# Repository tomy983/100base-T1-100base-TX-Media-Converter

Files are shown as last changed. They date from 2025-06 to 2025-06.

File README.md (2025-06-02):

# 100base-T1-100base-TX-Media-Converter
PCB designed to convert automotive ethernet 100base-T1 to 100base-TX ethernet

This is a corrected version (the picture shows the previous revision). The correction consists of a missing resistor to set the TJA1101B MDIO address.

Another issue I had during bring up was the ferrite bead FB1, which I originally selected of incorrect value. (The TJA1101B was reporting low voltage on register 25 bits 15 and 14 (UV_VDDD_3V3 and UV_VDDA_3V3). I corrected it in the published schematic, but it is untested. On my PCB I've just shorted it.

I've tested 2 of this board with Unshielded and not twisted wire (ideally should be Twisted - UTP) of 8 meters length, reaching a speed of 85Mbps. No dropped packets were observed.
The polarity of the 2 wire ethernet doesn't really matter (the slave will correct accordingly).
After this successful test I've proceeded testing with my PandarQT 3D lidar (which only has 100base-T1 interface) successfully.

No MDIO setup is needed (the configuration is all done via strapping resistors). Just bridge the solder bridges to select autonomous mode and also master or slave as needed.
While not required, if you need MDIO interface to check / set registers, keep in mind that while in autonomous mode the MDIO interface of TJA1101B will not work. Just set it to managed.

Is included the very rough Arduino sketch that I've used to interface with MDIO (bit banging).

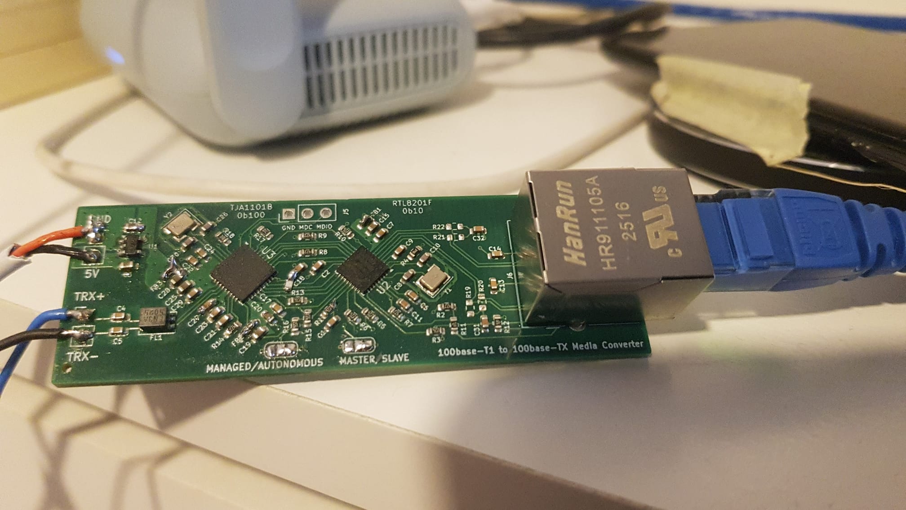
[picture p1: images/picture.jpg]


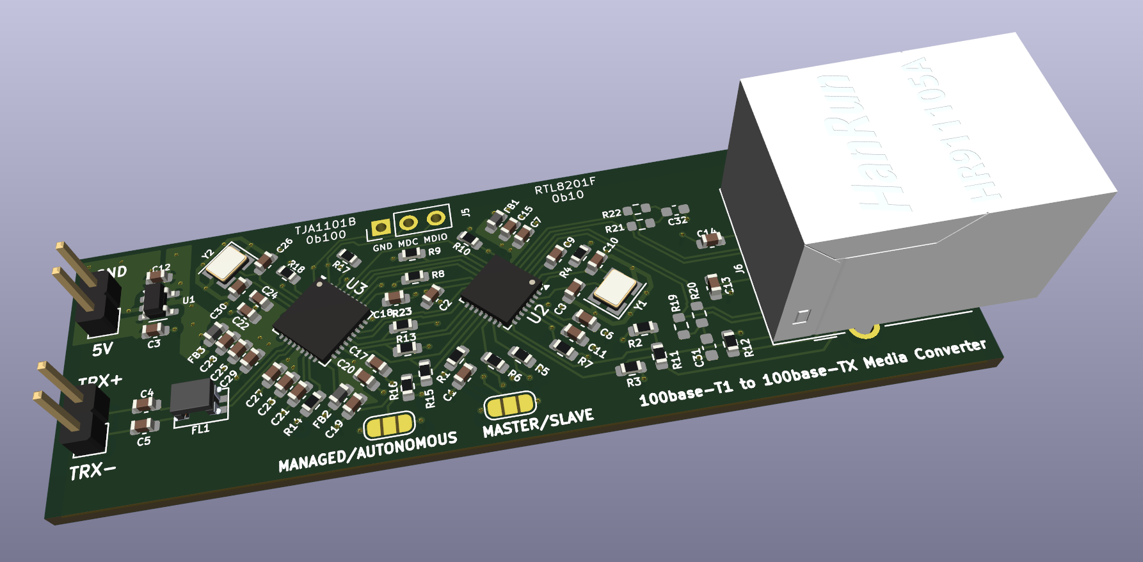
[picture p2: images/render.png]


Resources used for this project:

- https://www.nxp.com/downloads/en/schematics/RDDRONE-T1ADAPT-SCH.pdf
- https://github.com/NXPHoverGames/RDDRONE-T1ADAPT/blob/main/t1eth10Lpc/src/t1eth10Lpc.c
- https://github.com/ehntoo/100base-t1-converter
- https://www.nxp.com/document/guide/getting-started-with-the-rddrone-t1adapt-evaluation-board:GS-RDDRONE-T1ADAPT
- https://github.com/cioban/arduino-projects/blob/master/smi/smi.ino

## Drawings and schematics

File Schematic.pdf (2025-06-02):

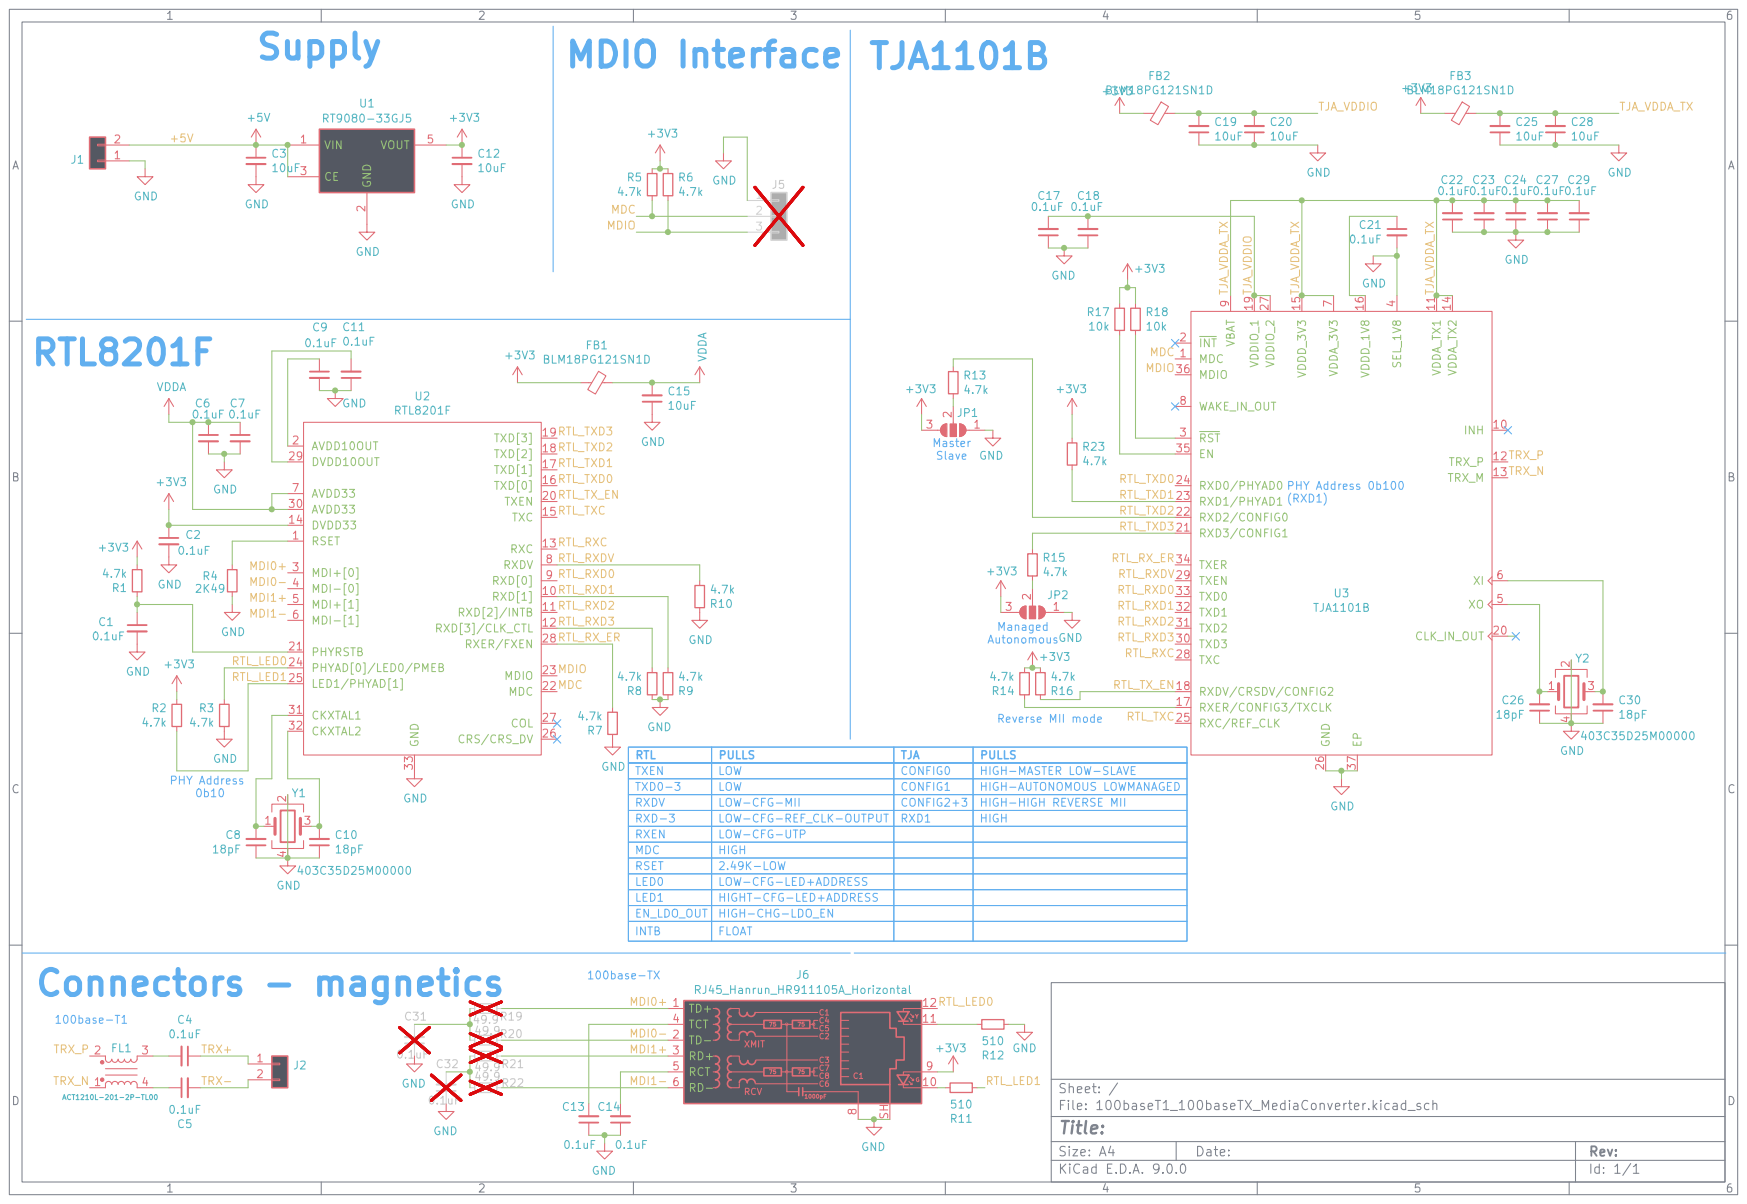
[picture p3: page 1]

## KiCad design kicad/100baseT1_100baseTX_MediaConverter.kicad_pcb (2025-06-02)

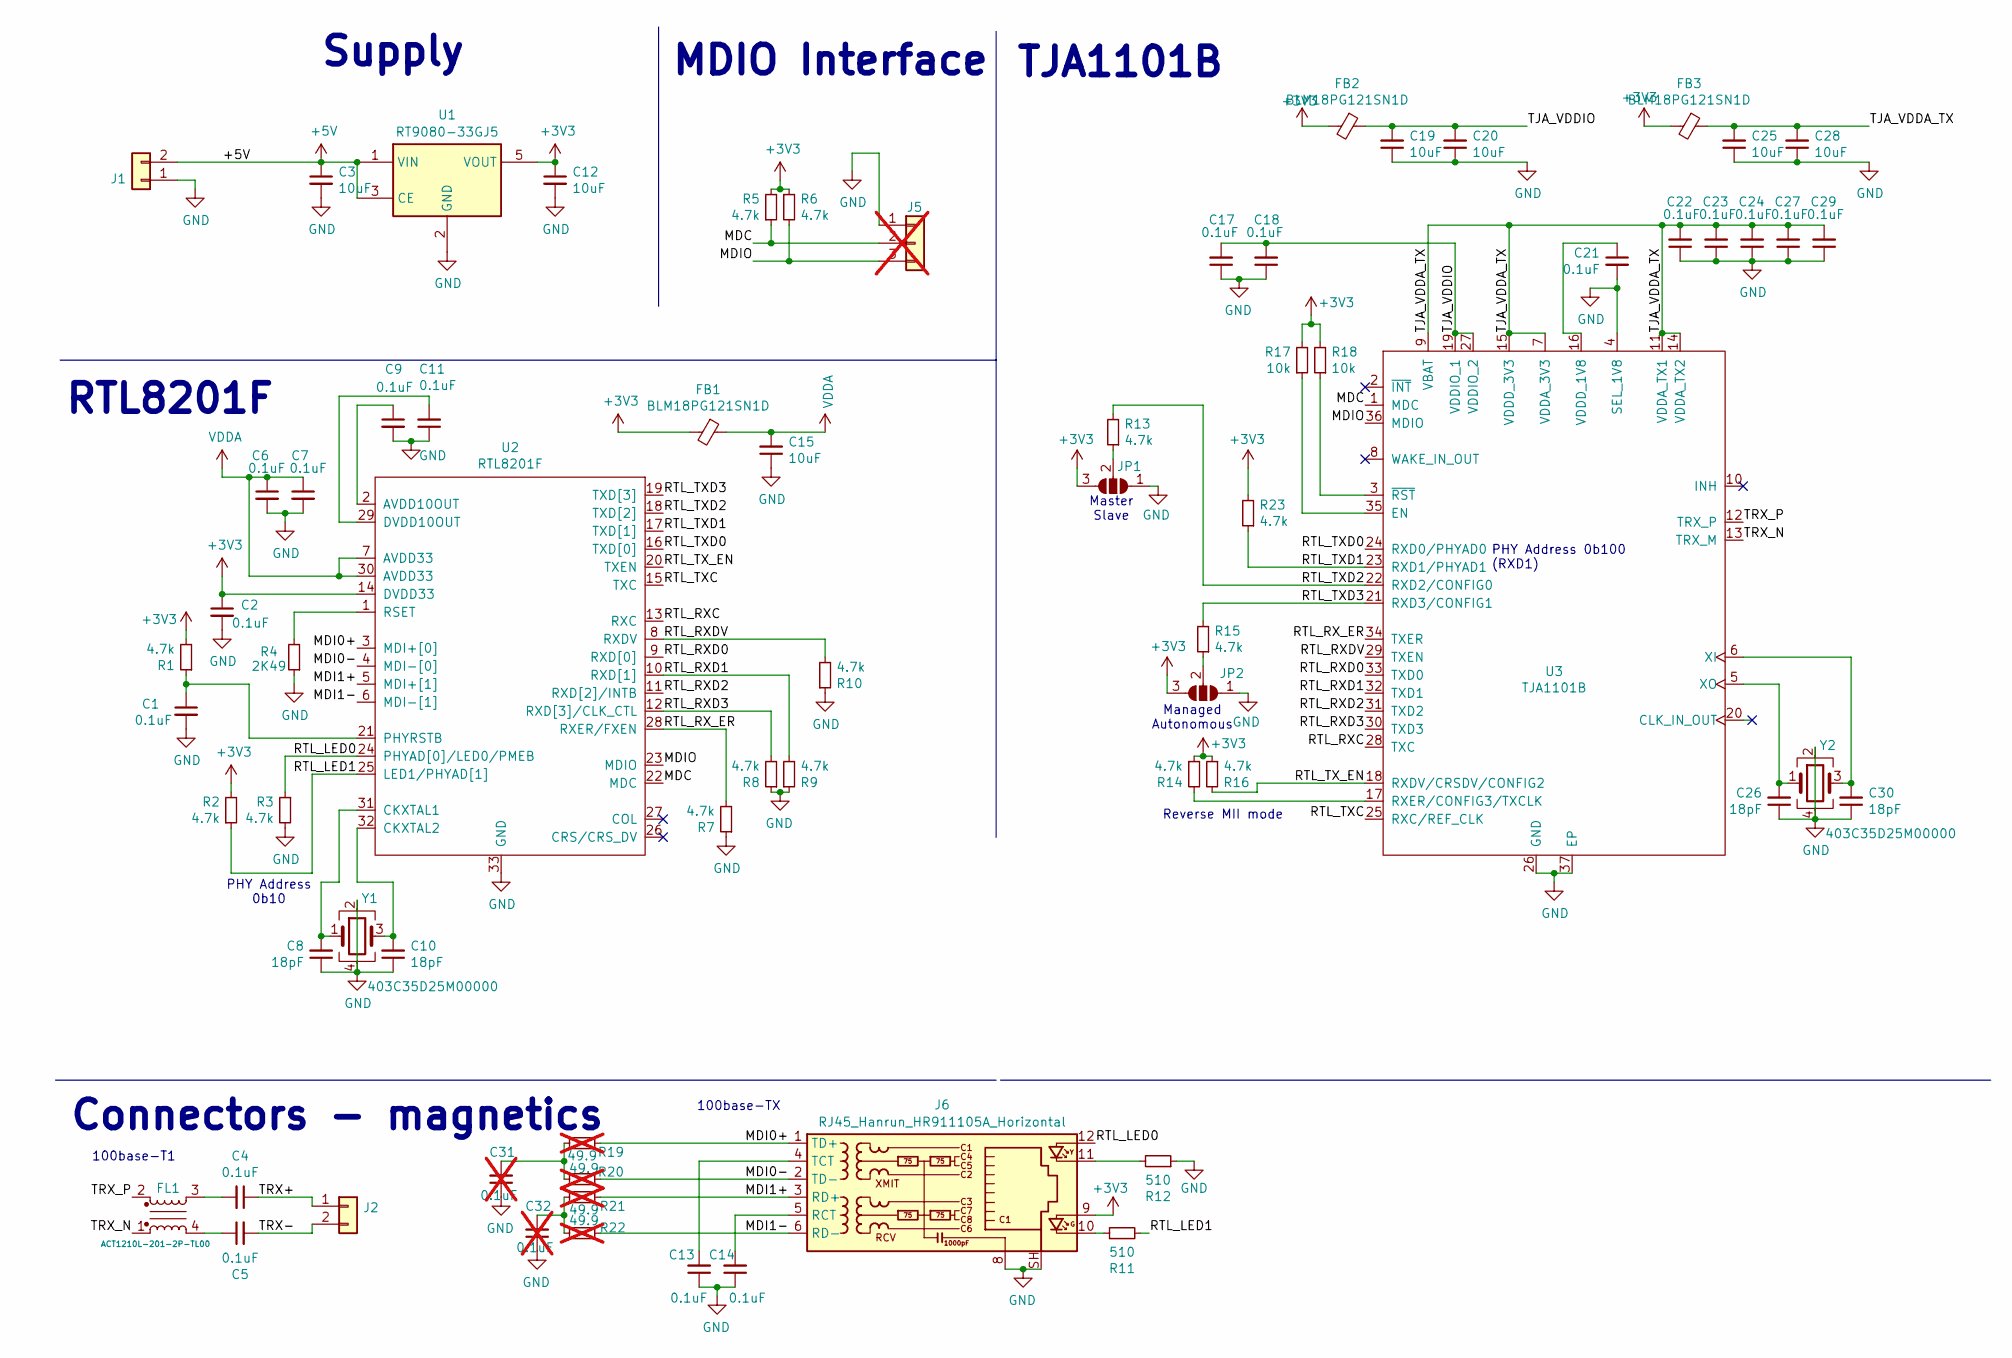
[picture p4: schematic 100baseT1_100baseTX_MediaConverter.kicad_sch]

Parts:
C1, C2, C4, C5, C6, C7, C9, C11, C13, C14, C17, C18, C21, C22, C23, C24, C27, C29: 0.1uF; C_0603_1608Metric
C3, C12, C15, C19, C20, C25, C28: 10uF; C_0603_1608Metric
C8, C10, C26, C30: 18pF; C_0603_1608Metric
C31, C32: 0.1uF; C_0603_1608Metric; not fitted
FB1, FB2, FB3: BLM18PG121SN1D; L_0603_1608Metric
FL1: ACT1210L-201-2P-TL00; ACT1210L
J1, J2: Conn_01x02; PinHeader_1x02_P2.54mm_Vertical
J5: Conn_01x03; PinHeader_1x03_P2.54mm_Vertical; not fitted
J6: RJ45_Hanrun_HR911105A_Horizontal
JP1, JP2: SolderJumper_3_Open; SolderJumper-3_P1.3mm_Open_RoundedPad1.0x1.5mm_NumberLabels
R1, R2, R3, R5, R6, R7, R8, R9, R10, R13, R14, R15, R16, R23: 4.7k; R_0603_1608Metric
R4: 2K49; R_0603_1608Metric
R11, R12: 510; R_0603_1608Metric
R17, R18: 10k; R_0603_1608Metric
R19, R20, R21, R22: 49.9; R_0603_1608Metric; not fitted
U1: RT9080-33GJ5; SOT-23-5; MPN XC6210B332MR-G
U2: RTL8201F; QFN-32-1EP_5x5mm_P0.5mm_EP3.3x3.3mm_ThermalVias
U3: TJA1101B; QFN-36-1EP_6x6mm_P0.5mm_EP3.7x3.7mm_ThermalVias
Y1, Y2: 403C35D25M00000; Crystal_SMD_SeikoEpson_FA238V-4Pin_3.2x2.5mm

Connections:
+3V3: C2.1, C12.1, FB1.2, FB2.2, FB3.2, J6.9, JP1.3 (B), JP2.3 (B), R1.2, R2.2, R5.2, R6.1, R14.1, R16.1, R17.2, R18.2, R23.2, U1.5 (VOUT), U2.14 (DVDD33)
+5V: C3.1, J1.2, U1.1 (VIN), U1.3 (CE)
/MDC: J5.2, R5.1, U2.22 (MDC), U3.1 (MDC)
/MDI0+: J6.1 (TD+), R19.2, U2.3 (MDI+[0])
/MDI0-: J6.2 (TD-), R20.2, U2.4 (MDI-[0])
/MDI1+: J6.3 (RD+), R21.2, U2.5 (MDI+[1])
/MDI1-: J6.6 (RD-), R22.2, U2.6 (MDI-[1])
/MDIO: J5.3, R6.2, U2.23 (MDIO), U3.36 (MDIO)
/RTL_LED0: J6.12, R3.1, U2.24 (PHYAD[0]/LED0/PMEB)
/RTL_LED1: R2.1, R11.2, U2.25 (LED1/PHYAD[1])
/RTL_RXC: U2.13 (RXC), U3.28 (TXC)
/RTL_RXD0: U2.9 (RXD[0]), U3.33 (TXD0)
/RTL_RXD1: R9.2, U2.10 (RXD[1]), U3.32 (TXD1)
/RTL_RXD2: U2.11 (RXD[2]/INTB), U3.31 (TXD2)
/RTL_RXD3: R8.2, U2.12 (RXD[3]/CLK_CTL), U3.30 (TXD3)
/RTL_RXDV: R10.2, U2.8 (RXDV), U3.29 (TXEN)
/RTL_RX_ER: R7.2, U2.28 (RXER/FXEN), U3.34 (TXER)
/RTL_TXC: U2.15 (TXC), U3.25 (RXC/REF_CLK)
/RTL_TXD0: U2.16 (TXD[0]), U3.24 (RXD0/PHYAD0)
/RTL_TXD1: R23.1, U2.17 (TXD[1]), U3.23 (RXD1/PHYAD1)
/RTL_TXD2: R13.2, U2.18 (TXD[2]), U3.22 (RXD2/CONFIG0)
/RTL_TXD3: R15.2, U2.19 (TXD[3]), U3.21 (RXD3/CONFIG1)
/RTL_TX_EN: R16.2, U2.20 (TXEN), U3.18 (RXDV/CRSDV/CONFIG2)
/TJA_VDDA_TX: C22.2, C23.2, C24.2, C25.2, C27.2, C28.2, C29.2, FB3.1, U3.7 (VDDA_3V3), U3.9 (VBAT), U3.11 (VDDA_TX1), U3.14 (VDDA_TX2), U3.15 (VDDD_3V3)
/TJA_VDDIO: C17.2, C18.2, C19.2, C20.2, FB2.1, U3.19 (VDDIO_1), U3.27 (VDDIO_2)
/TRX+: C4.1, J2.1
/TRX-: C5.2, J2.2
/TRX_N: FL1.1, U3.13 (TRX_M)
/TRX_P: FL1.2, U3.12 (TRX_P)
GND: C1.2, C2.2, C3.2, C6.2, C7.2, C8.1, C9.2, C10.1, C11.1, C12.2, C13.1, C14.1, C15.1, C17.1, C18.1, C19.1, C20.1, C21.2, C22.1, C23.1, C24.1, C25.1, C26.1, C27.1, C28.1, C29.1, C30.1, C31.1, C32.1, J1.1, J5.1, J6.8, J6.SH, JP1.1 (A), JP2.1 (A), R3.2, R4.1, R7.1, R8.1, R9.1, R10.1, R12.1, U1.2 (GND), U2.33 (GND), U3.4 (SEL_1V8), U3.26 (GND), U3.37 (EP), Y1.2, Y1.4, Y2.2, Y2.4
unnamed: C4.2, FL1.3
unnamed: C5.1, FL1.4
unnamed: C31.2, R19.1, R20.1
unnamed: C32.2, R21.1, R22.1
unnamed: J6.10, R11.1
unnamed: J6.11, R12.2
unnamed: C14.2, J6.5 (RCT)
unnamed: C13.2, J6.4 (TCT)
unnamed: JP1.2 (C), R13.1
unnamed: JP2.2 (C), R15.1
unnamed: C9.1, U2.2 (AVDD10OUT)
unnamed: C8.2, U2.31 (CKXTAL1), Y1.1
unnamed: C10.2, U2.32 (CKXTAL2), Y1.3
unnamed: C11.2, U2.29 (DVDD10OUT)
unnamed: C1.1, R1.1, U2.21 (PHYRSTB)
unnamed: R4.2, U2.1 (RSET)
unnamed: R17.1, U3.35 (EN)
unnamed: R14.2, U3.17 (RXER/CONFIG3/TXCLK)
unnamed: C21.1, U3.16 (VDDD_1V8)
unnamed: C30.2, U3.6 (XI), Y2.3
unnamed: C26.2, U3.5 (XO), Y2.1
unnamed: R18.1, U3.3 (~RST)
VDDA: C6.1, C7.1, C15.2, FB1.1, U2.7 (AVDD33), U2.30 (AVDD33)

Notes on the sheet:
100base-T1
Connectors - magnetics
PHY Address 0b100 (RXD1)
MDIO Interface
TJA1101B
Master Slave
Reverse MII mode
RTL8201F
100base-TX
Managed Autonomous
PHY Address 0b10
Supply

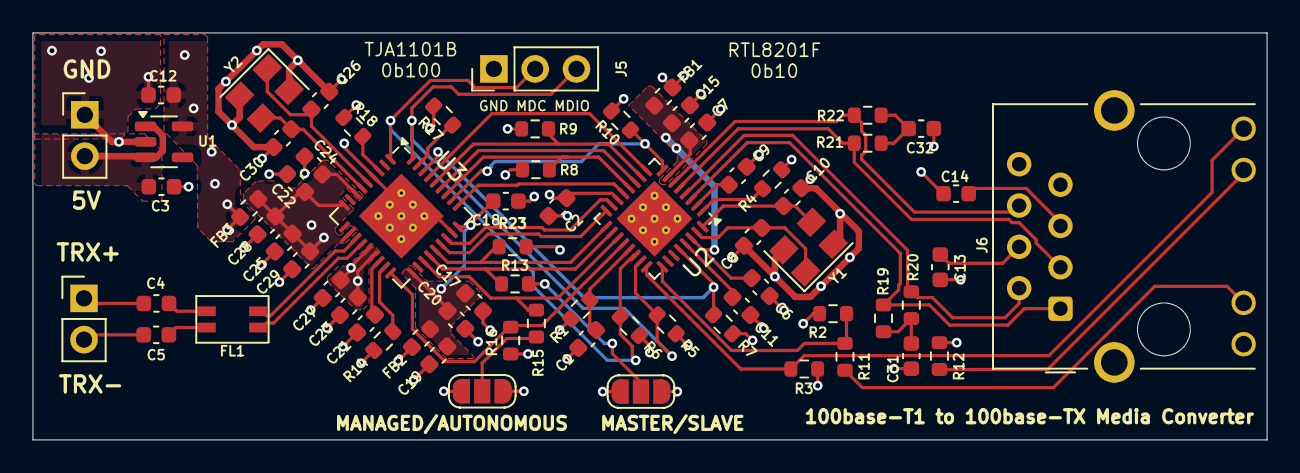
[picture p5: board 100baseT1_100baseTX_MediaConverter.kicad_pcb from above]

Board: 4 copper layers, 75.9 x 25.0 mm, 69 parts (0 on the bottom side), 53 nets.

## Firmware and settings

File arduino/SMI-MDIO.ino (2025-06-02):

#include <stdio.h>
#include <stdlib.h>
#include <stdint.h>


#define TJA_RESET_ERR "ERROR: TJA1101 not reset correctly\r\n"
#define TJA_NOT_STBY "ERROR: TJA1101 not in standby mode\r\n"
#define TJA_MASTER_MODE "TJA1101 Master mode\r\n"
#define TJA_SLAVE_MODE "TJA1101 Slave mode\r\n"
#define REINIT_TJA "TJA1101 re-init\r\n"
#define OK_TJA "TJA1101 con OK\r\n"
#define FAIL_TJA "TJA1101 con FAIL\r\n"
#define INIT_DONE_OK "Initialization done OK\r\n"


// SMI registers
#define SMI_CNTRL (uint8_t)0
#define SMI_STATUS (uint8_t)1
#define SMI_PHY_ID1 (uint8_t)2
#define SMI_PHY_ID2 (uint8_t)3
#define SMI_AUTO_NEG_ADV (uint8_t)4
#define SMI_AUTO_NEG_LNK (uint8_t)5
#define SMI_AUTO_NEG_EXP (uint8_t)6
#define SMI_AUTO_NEG_PNR (uint8_t)7
#define SMI_REG8 (uint8_t)8
#define SMI_REG9 (uint8_t)9
#define SMI_REG10 (uint8_t)10
#define SMI_REG11 (uint8_t)11
#define SMI_REG12 (uint8_t)12
#define SMI_REG13 (uint8_t)13
#define SMI_REG14 (uint8_t)14
#define SMI_EXT_STAT (uint8_t)15    // TJA1100
#define SMI_AUTO_MDIX (uint8_t)16   
#define SMI_MODE_CNTRL (uint8_t)17  
#define SMI_SPEC_MODE (uint8_t)18   // LAN8700
#define SMI_REG19 (uint8_t)19
#define SMI_REG24 (uint8_t)24
#define SMI_REG25 (uint8_t)25
#define SMI_INTREG (uint8_t)26
#define SMI_AUXMODE4 (uint8_t)26    
#define SMI_STAT_IND (uint8_t)27    // LAN8700
#define SMI_REG28 (uint8_t)28       // LAN8700
#define SMI_INT_SRC_LN (uint8_t)29  // LAN8700
#define SMI_INT_MSK (uint8_t)30     // LAN8700
#define SMI_PHY_CNTRL (uint8_t)31   /

#define SMI_EXT_CNTRL 17    // 0x11 TJA1100
#define SMI_CONFIG1 18      // 0x12 TJA1100
#define SMI_CONFIG2 19      // 0x13 TJA1100
#define SMI_SYM_ERR 20      // 0x14 TJA1100
#define SMI_INT_SRC_TJA 21  // 0x15 TJA1100
#define SMI_INT_ENA_TJA 22  // 0x16 TJA1100
#define SMI_COMM_STAT 23    // 0x17 TJA1100
#define SMI_GEN_STAT 24     // 0x18 TJA1100
#define SMI_EXTERN_STAT 25  // 0x19 TJA1100
#define SMI_LINK_FAIL 26    // 0x1A TJA1100
#define SMI_COM_CONF 27     // 0x1B TJA1101

// basic control register 0
#define SMI_0_RESET (1 << 15)
#define SMI_0_LOOPBACK (1 << 14)
#define SMI_0_SPD_10 ((0 << 13) | (0 << 6))
#define SMI_0_SPD_100 ((1 << 13) | (0 << 6))
#define SMI_0_SPD_1000 ((0 << 13) | (1 << 6))
#define SMI_0_SPD_MASK ((1 << 13) | (1 << 6))
#define SMI_0_AUTONEG_EN (1 << 12)  // Not supported by TJA1100
#define SMI_0_POWER_DOWN (1 << 11)  // ISOLATE should be zero
#define SMI_0_ISOLATE (1 << 10)     // should be off for normal operation
#define SMI_0_RE_AUTO (1 << 9)      // Not supported by TJA1100
#define SMI_0_DUPLEX (1 << 8)       // Only supported by TJA1100
#define SMI_0_COLL_TST (1 << 7)     // Not supported by TJA1100
#define SMI_0_UNIDIR (1 << 5)

// basic status register 1
#define SMI_1_100BASE_T4 (1 << 15)
#define SMI_1_100BASE_X_FD (1 << 14)
#define SMI_1_100BASE_X_HD (1 << 13)
#define SMI_1_10MBPS_FD (1 << 12)
#define SMI_1_10MBPS_HD (1 << 11)
#define SMI_1_100BASE_T2_FD (1 << 10)
#define SMI_1_100BASE_T2_HD (1 << 9)
#define SMI_1_EXT_STAT (1 << 8)
#define SMI_1_UNI_ABLE (1 << 7)
#define SMI_1_MF_PRE_SUP (1 << 6)
#define SMI_1_AUTONEG_CMP (1 << 5)
#define SMI_1_REM_FAULT (1 << 4)
#define SMI_1_AUTONEG_ABLE (1 << 3)
#define SMI_1_LINK_STAT (1 << 2)
#define SMI_1_JAB_DET (1 << 1)
#define SMI_1_EXT_CAP (1 << 0)

// PHY identifier register 1
#define SMI_2_TJA1101 0x0180
#define SMI_2_BCM5241 0x0143

// PHY identifier register 2
#define SMI_3_TJA1101 0xDD01
#define SMI_3_BCM5241 0xBC31

// PHY SMI_EXT_CNTRL TJA1100
#define SMI_17_LINK_CNTRL (1 << 15)
#define SMI_17_NOCHANGE (0x0 << 11)
#define SMI_17_NORMAL (0x3 << 11)
#define SMI_17_STBY (0xC << 11)
#define SMI_17_SLEEP_REQ (0xB << 11)
#define SMI_17_PWR_MASK (0xF << 11)
#define SMI_17_TRAIN (1 << 9)
#define SMI_17_TEST1 (1 << 6)
#define SMI_17_TEST2 (2 << 6)
#define SMI_17_TEST3 (3 << 6)
#define SMI_17_TEST4 (4 << 6)
#define SMI_17_TEST5 (5 << 6)
#define SMI_17_TEST6 (6 << 6)
#define SMI_17_TEST7 (7 << 6)
#define SMI_17_CABLE_TST (1 << 5)
#define SMI_17_INT_LPB (0 << 3)
#define SMI_17_EXT1_LPB (1 << 3)
#define SMI_17_EXT2_LPB (2 << 3)
#define SMI_17_REM_LPB (3 << 3)
#define SMI_17_CONFIG_EN (1 << 2)
#define SMI_17_CONFIG_INH (1 << 1)
#define SMI_17_WAKE_REQ (1 << 0)  // transmit idle symbols as bus wake-up request

// PHY SMI_CONFIG1  TJA1100
#define SMI_18_MASTER (1 << 15)
#define SMI_18_AUTO_OP (1 << 14)
#define SMI_18_LINK_15M (1 << 13)  // cable length > 15 m
#define SMI_18_TX_500MV (0 << 10)
#define SMI_18_TX_750MV (1 << 10)
#define SMI_18_TX_1000MV (2 << 10)
#define SMI_18_TX_1250MV (3 << 10)
#define SMI_18_MII_MODE (0 << 8)
#define SMI_18_RMII_50MHZ (1 << 8)
#define SMI_18_RMII_25MHZ (2 << 8)
#define SMI_18_REV_MII (3 << 8)
#define SMI_18_MII_DRV_RED (1 << 7)  // reduced strength MII output driver
#define SMI_18_LEDLINK (0 << 4)
#define SMI_18_LEDFRAME (1 << 4)
#define SMI_18_LEDSYMERR (2 << 4)
#define SMI_18_LEDCRS (3 << 4)
#define SMI_18_LED_EN (1 << 3)
#define SMI_18_CNFG_WAKE (1 << 2)  // ratiometric input threshold, absolute if zero
#define SMI_18_AUTO_PWD (1 << 1)   // autonomous power-down enabled

// PHY SMI CONFIG2 TJA1100
#define SMI_19_PHYAD_MASK (0x1F << 11)  // readback of scrambler key
#define SMI_19_SNR_AV32 (0 << 9)        // signal to noise ratio averaging over  32 symbols
#define SMI_19_SNR_AV64 (1 << 9)        // signal to noise ratio averaging over  64 symbols
#define SMI_19_SNR_AV128 (2 << 9)       // signal to noise ratio averaging over 128 symbols
#define SMI_19_SNR_AV256 (3 << 9)       // signal to noise ratio averaging over 256 symbols
#define SMI_19_WLIM_NO (0 << 6)         // no warning
#define SMI_19_WLIM_A (1 << 6)          // Class A SNR warning limit
#define SMI_19_WLIM_B (2 << 6)          // Class B SNR warning limit
#define SMI_19_WLIM_C (3 << 6)          // Class C SNR warning limit
#define SMI_19_WLIM_D (4 << 6)          // Class D SNR warning limit
#define SMI_19_WLIM_E (5 << 6)          // Class E SNR warning limit
#define SMI_19_WLIM_F (6 << 6)          // Class F SNR warning limit
#define SMI_19_WLIM_G (7 << 6)          // Class G SNR warning limit
#define SMI_19_SNR_F_NL (0 << 3)        // signal to noise ratio fail limit - no limit
#define SMI_19_SNR_F_CLA (1 << 3)       // signal to noise ratio fail limit - Class A
#define SMI_19_SNR_F_CLB (2 << 3)       // signal to noise ratio fail limit - Class B
#define SMI_19_SNR_F_CLC (3 << 3)       // signal to noise ratio fail limit - Class C
#define SMI_19_SNR_F_CLD (4 << 3)       // signal to noise ratio fail limit - Class D
#define SMI_19_SNR_F_CLE (5 << 3)       // signal to noise ratio fail limit - Class E
#define SMI_19_SNR_F_CLF (6 << 3)       // signal to noise ratio fail limit - Class F
#define SMI_19_SNR_F_CLG (7 << 3)       // signal to noise ratio fail limit - Class G
#define SMI_19_JUMBO_EN (1 << 2)        // enable packets up to 16 kB instead of 4 kB
#define SMI_19_SLP_T_04 (0 << 0)        // sleep request timeout 0.4 ms
#define SMI_19_SLP_T_1 (1 << 0)         // sleep request timeout 1 ms
#define SMI_19_SLP_T_4 (2 << 0)         // sleep request timeout 4 ms
#define SMI_19_SLP_T_16 (3 << 0)        // sleep request timeout 16 ms

// PHY SMI COM STAT TJA1100
#define SMI_23_LINK_STAT (1 << 15)     // Link OK
#define SMI_23_TX_MODE_MASK (3 << 13)  // TX mode mask
#define SMI_23_TX_MODE_DIS (0 << 13)   // transmitter disabled
#define SMI_23_TX_MODE_N (1 << 13)     // transmitter in SEND_N mode
#define SMI_23_TX_MODE_I (2 << 13)     // transmitter in SEND_I mode
#define SMI_23_TX_MODE_Z (3 << 13)     // transmitter in SEND_Z mode
#define SMI_23_LOC_RCVR_ST (1 << 12)   // local receiver OK
#define SMI_23_REM_RCVR_ST (1 << 11)   // remote receiver OK
#define SMI_23_SCR_LOCKED (1 << 10)    // descrambler locked
#define SMI_23_SSD_ERR (1 << 9)        // SSD error detected
#define SMI_23_ESD_ERR (1 << 8)        // ESD error detected
#define SMI_23_SNR_MASK (7 << 5)       // Signal to noise mask
#define SMI_23_SNR_F_WRS (0 << 5)      // worse than Class A
#define SMI_23_SNR_F_CLA (1 << 5)      // Class A
#define SMI_23_SNR_F_CLB (2 << 5)      // Class B
#define SMI_23_SNR_F_CLC (3 << 5)      // Class C
#define SMI_23_SNR_F_CLD (4 << 5)      // Class D
#define SMI_23_SNR_F_CLE (5 << 5)      // Class E
#define SMI_23_SNR_F_CLF (6 << 5)      // Class F
#define SMI_23_SNR_F_CLG (7 << 5)      // Class G
#define SMI_23_REC_NO_ERR (1 << 4)     // no receive error detected
#define SMI_23_TRAN_NO_ERR (1 << 3)    // no transmitt error detected
#define SMI_23_PHY_STAT_MSK (7 << 0)   // phy state mask
#define SMI_23_PHY_IDLE (0 << 0)       // idle
#define SMI_23_PHY_INIT (1 << 0)       // initialized
#define SMI_23_PHY_CONFIG (2 << 0)     // configured
#define SMI_23_PHY_OFFLINE (3 << 0)    // Offline
#define SMI_23_PHY_ACTIVE (4 << 0)     // Active
#define SMI_23_PHY_ISOLATE (5 << 0)    // isolate
#define SMI_23_PHY_CABLE (6 << 0)      // cable test
#define SMI_23_PHY_TEST (7 << 0)       // test mode


#define MDCIP D5  // wiringPi PIN for MDCIP
#define MDIO D6   // wiringPi PIN for MDIO

byte add_rtl = 0b00010;
byte add_tja = 0b00100;


int smi_init(void) {
  pinMode(MDCIP, OUTPUT);
  pinMode(MDIO, OUTPUT);
  return 0;
}


/*! Generates a rising edge pulse on IP175 MDC */
void pulse_mdcip(void) {
  digitalWrite(MDCIP, 0);
  delay(1);
  digitalWrite(MDCIP, 1);
  delay(1);
}


/*! Performs a smi write */
void write_smi(uint8_t phy, uint8_t reg, uint16_t data) {
  uint8_t byte;
  uint16_t word;

  void (*pulse_mdc)(void);
  pulse_mdc = pulse_mdcip;

  /* MDIO pin is output */
  pinMode(MDIO, OUTPUT);

  digitalWrite(MDIO, 1);
  for (byte = 0; byte < 32; byte++)
    pulse_mdc();

  /* Stat code */
  digitalWrite(MDIO, 0);
  pulse_mdc();
  digitalWrite(MDIO, 1);
  pulse_mdc();

  /* Write OP Code */
  digitalWrite(MDIO, 0);
  pulse_mdc();
  digitalWrite(MDIO, 1);
  pulse_mdc();

  /* PHY address - 5 bits */
  for (byte = 0x10; byte != 0; byte = byte >> 1) {
    if (byte & phy)
      digitalWrite(MDIO, 1);
    else
      digitalWrite(MDIO, 0);
    pulse_mdc();
  }
  /* REG address - 5 bits */
  for (byte = 0x10; byte != 0; byte = byte >> 1) {
    if (byte & reg)
      digitalWrite(MDIO, 1);
    else
      digitalWrite(MDIO, 0);

    pulse_mdc();
  }
  /* Turn around bits */
  digitalWrite(MDIO, 1);
  pulse_mdc();
  digitalWrite(MDIO, 0);
  pulse_mdc();

  /* Data - 16 bits */
  for (word = 0x8000; word != 0; word = word >> 1) {
    if (word & data)
      digitalWrite(MDIO, 1);
    else
      digitalWrite(MDIO, 0);

    pulse_mdc();
  }

  /* This is needed for some reason... */
  pulse_mdc();
  /* Stay in 0 state */
  //  MDCIP = 0;
}

uint16_t read_smi(uint8_t phy, uint8_t reg) {
  uint8_t byte;
  uint16_t word, data;

  void (*pulse_mdc)(void);

  pulse_mdc = pulse_mdcip;

  /* MDIO pin is output */
  pinMode(MDIO, OUTPUT);

  digitalWrite(MDIO, 1);
  for (byte = 0; byte < 32; byte++)
    pulse_mdc();

  /* Stat code */
  digitalWrite(MDIO, 0);
  pulse_mdc();
  digitalWrite(MDIO, 1);
  pulse_mdc();

  /* Read OP Code */
  digitalWrite(MDIO, 1);
  pulse_mdc();
  digitalWrite(MDIO, 0);
  pulse_mdc();

  /* PHY address - 5 bits */
  for (byte = 0x10; byte != 0;) {
    if (byte & phy)
      digitalWrite(MDIO, 1);
    else
      digitalWrite(MDIO, 0);

    pulse_mdc();

    byte = byte >> 1;
  }
  /* REG address - 5 bits */
  for (byte = 0x10; byte != 0;) {
    if (byte & reg)
      digitalWrite(MDIO, 1);
    else
      digitalWrite(MDIO, 0);

    pulse_mdc();

    byte = byte >> 1;
  }
  /* Turn around bits */
  /* MDIO now is input */
  pinMode(MDIO, INPUT_PULLUP);
  pulse_mdc();
  pulse_mdc();
  /* Data - 16 bits */
  data = 0;
  for (word = 0x8000; word != 0;) {

    if (digitalRead(MDIO))
      data |= word;

    pulse_mdc();


    word = word >> 1;
  }

  /* This is needed for some reason... */
  pulse_mdc();
  /* Stay in 0 state */
  //  MDCIP = 0;

  return data;
}

void binprintf(int v) {
  unsigned int mask = 1 << ((sizeof(uint16_t) << 3) - 1);
  while (mask) {
    printf("%d", (v & mask ? 1 : 0));
    mask >>= 1;
  }
}

void setup() {
  uint16_t reg_val = 0;
  // start serial port at 9600 bps:
  Serial.begin(115200);
  smi_init();
  delay(6000);
  Serial.print("Ready...\n\n\n\n");
  reg_val = read_smi(2, 0x00);
  Serial.print("reg_val=[0x");
  Serial.print(reg_val, HEX);
  Serial.print("]\n");


  uint16_t val;
  write_smi(add_tja, SMI_CNTRL, SMI_0_RESET);  // send reset to TJA1101
  val = read_smi(add_tja, SMI_CNTRL);
  if (!(((val & SMI_0_SPD_MASK) == SMI_0_SPD_100) && (val & SMI_0_DUPLEX))) {
    printf(TJA_RESET_ERR);
  }

  printregister(add_tja, SMI_INT_SRC_TJA);              // read interrupt source
  // printf(" SMI_INT_SRC_TJA");
  printregister(add_tja, SMI_INT_SRC_TJA);              // read interrupt source
  // printf(" SMI_INT_SRC_TJA");
  printregister(add_tja, SMI_INT_SRC_TJA);              // read interrupt source
  // printf(" SMI_INT_SRC_TJA");
  // printf("\nEnabling configuration on reg 17 BIT 2.....\n");
  printregister(add_tja, SMI_EXT_CNTRL);                // read interrupt source
  // printf(" chech config disabled... SMI_EXT_CNTRL");
  write_smi(add_tja, SMI_EXT_CNTRL, SMI_17_CONFIG_EN);  // select mode TJA1101
  printregister(add_tja, SMI_EXT_CNTRL);                // read interrupt source
  // printf(" SMI_EXT_CNTRL");
  // printf("\nIs configuration enabled??\n");
  // write_smi(add_tja, SMI_CONFIG1, (SMI_18_REV_MII | (1 << 7)));

  printregister(add_tja, SMI_CONFIG1);

  // write_smi(add_tja, SMI_CNTRL, SMI_0_LOOPBACK);  // loopback
  // write_smi(add_tja, SMI_EXT_CNTRL, ((0x2 << 3) | SMI_17_CONFIG_EN));


  // printf(" SMI_CONFIG1");
  write_smi(add_tja, SMI_COM_CONF, (1 << 15));                                                // fix TJA1101

  delay(80);                                                                                  // delay about 10 ms
  write_smi(add_tja, SMI_EXT_CNTRL, (SMI_17_LINK_CNTRL | SMI_17_NORMAL | SMI_17_CONFIG_EN));  // select normal mode TJA1101

  printregister(add_tja, SMI_EXT_CNTRL);  // read interrupt source
                                          //  printf(" SMI_EXT_CNTRL");
  /*
  */
  write_smi(add_rtl, SMI_CNTRL, SMI_0_RESET);  // send reset
  write_smi(add_rtl, 31, (0x7 << 0));          //Set page 7

  delay(80);
  write_smi(add_rtl, 16, 0b0000111111110010);
  // write_smi(add_rtl, SMI_CNTRL, SMI_0_LOOPBACK);  // loopback rtl
  // write_smi(add_rtl, SMI_REG28,  ((0 << 1) | (0 << 2)));  // loopback rtl
  write_smi(add_rtl, SMI_CNTRL, (SMI_0_AUTONEG_EN));
  //write_smi(add_rtl, SMI_CNTRL, 0b0010000100000000);
}

void printregister(uint8_t add, uint8_t reg) {
  uint16_t reg_val = read_smi(add, reg);
  if (add == add_tja) {
    printf("\nTJA1101B,Register:%2d,Value:", reg);
  } else {
    printf("\nRTL8201F,Register:%2d,Value:", reg);
  }
  binprintf(reg_val);
}


void loop() {
  uint16_t reg_val = 0;

  delay(1000);

  printregister(add_rtl, 0);
  // printf(" Basic Mode Control Register ");
  printregister(add_rtl, 1);
  // printf(" Basic Mode Status Registerr ");
  printregister(add_rtl, 4);
  // printf(" Auto-Negotiation Advertisement register ");
  printregister(add_rtl, 5);
  // printf(" Auto-Negotiation Link parter ability register ");
  printregister(add_rtl, 6);
  // printf(" Auto-Negotiation Expansion register ");
  // printregister(add_rtl, 23);
  // printf(" Force Link and Bypass Scrambler register ");
  // printregister(add_rtl, 24);
  // printf(" Receiver Error Mask register ");
  // printregister(add_rtl, 28);
  // printf(" Fiber Mode and Loopback register ");
  // printregister(add_rtl, 30);
  // printf(" SNR Display register ");
  // printregister(add_rtl, 31);
  //  printf(" Page Select register ");
  printregister(add_rtl, 16);
  printf(" RMII Mode Setting register ");
  // printregister(add_rtl, 17);
  // printf(" Customized LED settings register ");
  // printregister(add_rtl, 18);
  // printf(" Led Enable register ");
  printregister(add_rtl, 19);
  printf(" Package indicator & LED Function register ");
  // printregister(add_rtl, 20);
  // printf(" MII TX Isolate register ");
  printregister(add_rtl, 31);
  printf(" Register 31 Page Select Register  ");

  printregister(add_tja, 0);
  // printf(" Basic control register ");
  printregister(add_tja, 1);
  // printf(" Basic status register ");
  printregister(add_tja, 15);
  // printf(" Extended status register ");
  printregister(add_tja, 17);
  // printf(" Extended control register ");
  printregister(add_tja, 18);
  // printf(" Configuration register 1 ");
  printregister(add_tja, 19);
  // printf(" Configuration register 2 ");
  printregister(add_tja, 20);
  // printf(" Symbol error counter register ");
  printregister(add_tja, 21);
  // printf(" Interrupt source register ");
  printregister(add_tja, 22);
  // printf(" Interrupt source register ");
  printregister(add_tja, 23);
  // printf(" Communication status register ");
  printregister(add_tja, 24);
  // printf(" General status register ");
  printregister(add_tja, 25);
  // printf(" External status register ");
  printregister(add_tja, 26);
  // printf(" Link fail counter register ");
  printregister(add_tja, 27);
  // printf(" Common configuration register ");
  printregister(add_tja, 28);
  // printf(" Configuration register 3 ");/* */
}

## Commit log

2025-06-02 Update and rename 100baseT1_100baseTX_MediaConverter.kicad_pcb to kicad/100baseT1_100baseTX_MediaConverter.kicad_pcb
    [100baseT1_100baseTX_MediaConverter.kicad_pcb]
2025-06-02 Update and rename 100baseT1_100baseTX_MediaConverter.kicad_sch to kicad/100baseT1_100baseTX_MediaConverter.kicad_sch
    [100baseT1_100baseTX_MediaConverter.kicad_sch]
